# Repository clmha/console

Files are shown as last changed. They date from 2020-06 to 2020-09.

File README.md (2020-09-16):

# Console
Ce projet est une console (code de projet CN1) avec des prises électriques faite sur-mesure pour aller en arrière du canapé. Il est inspiré du projet "Console Table" de [Build Something](https://www.buildsomething.com/plans/P1CFF7829247E55CF/Console-Table).

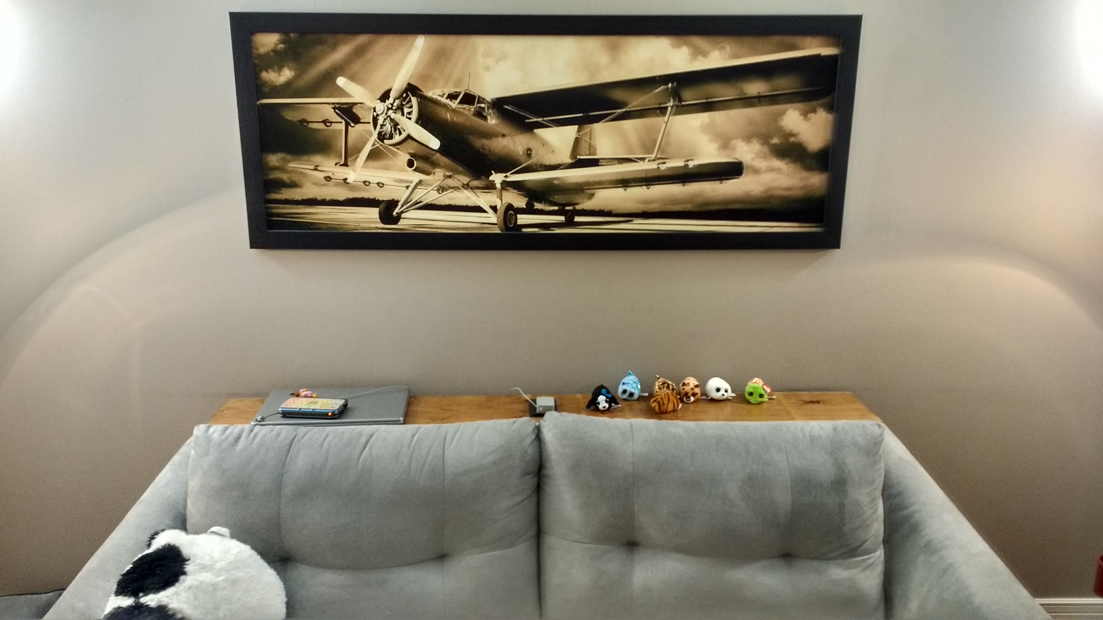
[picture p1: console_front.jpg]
Face de la Console

*Figure 1 - Vue de face*

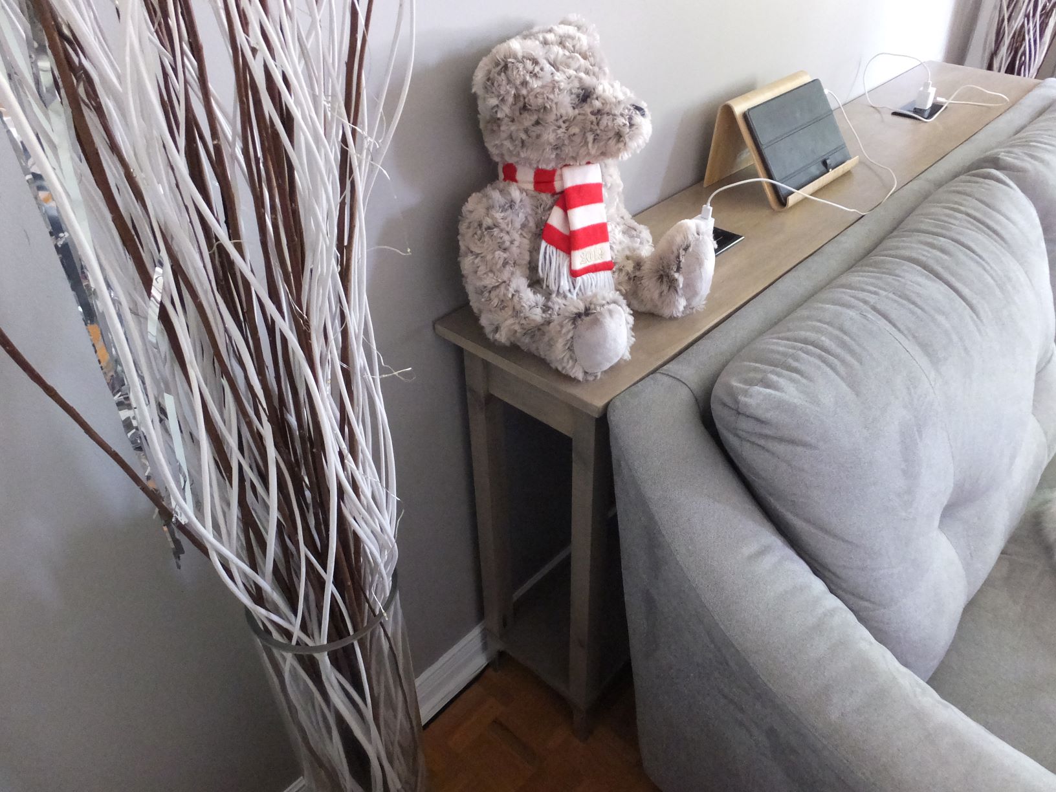
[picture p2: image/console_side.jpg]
Côté de la Console

*Figure 2 - Vue de côté*

Vous trouverez la liste des matériaux et de la quincaillerie nécessaires au sein de [CN1-MFG-001]. Hormi les outils de base (p. ex. ruban à mesurer), vous aurez également besoin des items suivants :

* Gabarit pour faire des trous en angle;
* Perceuse/visseuse;
* Scie circulaire pour la découpe grossière des panneaux;
* Banc de scie pour la découpe finale des panneaux;
* Scie à onglet pour découper précisement les lattes et les planches;
* Scie sauteuse pour découper les trous pour les prises électriques.

# Liste des documents
* CN1-ASY-001.pdf : dessin d'ensemble du projet avec la liste des pièces;
* CN1-MFG-001.pdf : le coût du projet;
* CN1-PRT-XYZ.pdf : le dessin de définition de la pièce numéro XYZ (notez que les pièces triviales n'ont pas de dessin de définition);
* CN1-REQ-001.pdf : le cahier des charges du projet.

# Environnement de développement
* Windows 10 comme système d'exploitation;
* QCAD Professional pour les dessins techniques;
* LibreOffice 6.* pour les documents;
* PDFtk pour manipuler les fichiers PDF;
* MinGW (mingw32-base-bin 2013072200) pour les outils de développement de base.

# Construire les artefacts
Avec l'environnement de développement correct, il vous suffit de lancer la commande "mingw32-make" depuis une invite de commande cmd.exe à la racine du projet et les documents seront générés dans le répertoire "build".

En cas d'erreurs "'X' n'est pas reconnu en tant que commande interne ou externe [...]", vérifiez que les exécutables de LibreOffice, QCAD, PDFtk et MinGW sont dans votre PATH.

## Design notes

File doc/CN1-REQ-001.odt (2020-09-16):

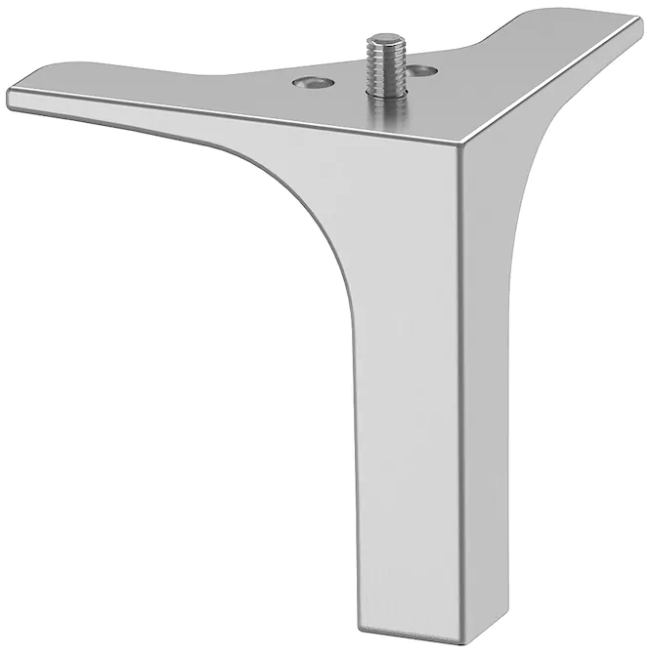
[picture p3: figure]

Figure 2 NANNARP aluminium (IKEA P/N 502.935.95) [IK00]

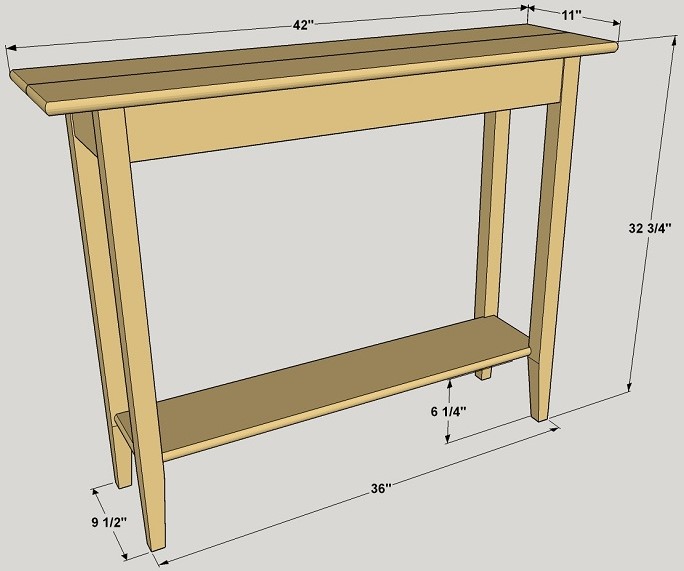
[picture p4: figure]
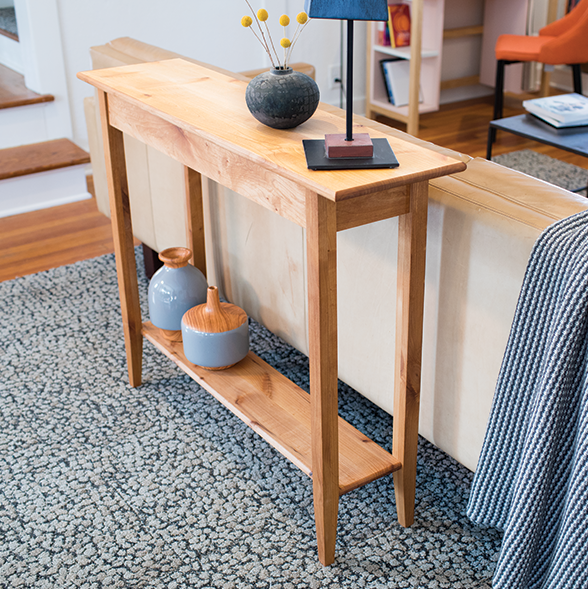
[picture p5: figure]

Figure 1 Exemple de console [BS00]

Cahier des charges

CN1-REQ-001 MOD 2

Clément Hamel

2020-09-16

# Définitions

po Pouce

# Références

BS00: buildsomething, Console Table, 2017, https://www.buildsomething.com/plans/P1CFF7829247E55CF/Console-Table

IK00: IKEA, IKEA, 2020, https://www.ikea.com/

# Vision

Nous souhaitons une console pour aller en arrière du canapé dans le salon et avec des prises électriques pour nous permettre de recharger nos appareils électroniques. Comme exemple ce qui nous plairait, il y a la conception illustrée dans la Figure 1.

# Exigences

## Longueur

La longueur du meuble doit être de 69 po, comme notre canapé.

## Hauteur

La hauteur du meuble doit être de 31 po afin que le plateau soit à la même hauteur que le dos de notre canapé.

## Profondeur

La profondeur du meuble doit être de :

- au moins 8 po (±1/8) afin de pouvoir poser les pattes; et
- au plus 10 po afin de ne pas trop empiéter l’espace du salon.

## Structure

### Portée

La portée des tablettes/plateaux entre leurs supports doit être inférieure ou égale à 36 po.

### Dépassement

Les tablettes/plateaux ne doivent pas dépasser de leurs supports plus que leur épaisseur.

## Finition

### Pattes

Le meuble doit avoir les pieds similaires à ceux de nos autres meubles du salon afin d’avoir un salon à l’apparence consistante (c.f. Figure 2).

### Bois

Le meuble doit avoir une couleur et un motif similaire à nos autres meubles du salon afin d’avoir un ensemble à l’apparence consistante.

## Électricité

Le meuble doit avoir au moins deux prises électriques accessible depuis les personnes assises dans le canapé afin qu’ils puissent recharger leurs appareils électroniques personnels.

## Sécurité

Les chats ne doivent pas pouvoir accéder aux parties sous haute-tension du meuble. Ils aiment bien se promener sous le meuble, et nous ne souhaitons pas que leur curiosité cause leur mort.

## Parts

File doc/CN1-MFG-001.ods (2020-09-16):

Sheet: Planifié
Item | Qté | Source | Prix unitaire HT | Rabais | Prix HT | Remarques
Bande de chant érable 13/16"x25' | 2 | BMR | 6,98 $ |  | 13,96 $
Panneau de particules plaqué érable 11/16"x4'x8' | 1 | BMR | 56,99 $ |  | 56,99 $
Latte 2x2x8’ de pin blanc | 2 | BMR | 5,99 $ |  | 11,98 $
Planche 1x4x6' de pin blanc | 1 | BMR | 4,99 $ |  | 4,99 $
Planche 1x4x8’ de pin blanc | 1 | BMR | 6,99 $ |  | 6,99 $
Boîte électrique rectangulaire avec oreilles 2"x3"x2 1/2" | 2 | (Estimation) | 3,00 $ |  | 6,00 $
Prise électrique double | 2 | (Estimation) | 2,00 $ |  | 4,00 $
Plaque électrique pour prise double | 2 | (Estimation) | 1,50 $ |  | 3,00 $
Cordon d’alimentation d’ordinateur 6 pi | 1 | (Estimation) | 10,00 $ |  | 10,00 $
Fil électrique AWG14 10 m | 1 | (Estimation) | 35,00 $ |  | 35,00 $
Patte Nannarp 2 mcx | 2 | IKEA | 10,00 $ |  | 20,00 $
Pré-teinture 1 qt | 1 | (Estimation) | 17,00 $ |  | 17,00 $
Teinture couleur de base 1 qt | 1 | (Estimation) | 17,00 $ |  | 17,00 $
Teinture couleur naturel 1 qt | 1 | (Estimation) | 17,00 $ |  | 17,00 $ | Pour pouvoir adapter la couleur de base aux différentes essences de bois.
Vernis transparent 1 qt | 1 | (Estimation) | 23,00 $ |  | 23,00 $
Vis à métal #6 5/8" ~10 mcx | 1 | (Estimation) | 2,89 $ |  | 2,89 $
Vis pour perçage à angle à filetage grossier #8 1" BT100 | 1 | (Estimation) | 7,00 $ |  | 7,00 $
Vis pour perçage à angle à filetage grossier #8 1 1/4" BT100 | 1 | (Estimation) | 7,50 $ |  | 7,50 $
Sous-total HT |  |  |  |  | 264,30 $
TPS |  |  |  |  | 13,22 $
TVQ |  |  |  |  | 26,36 $
Total TTC |  |  |  |  | 303,88 $

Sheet: TQC
Item | Qté | Source | Prix unitaire HT | Rabais | Prix HT | Remarques
Bande de chant érable 13/16"x25' | 1 | BMR | 6,98 $ | 10,00% | 6,28 $
Bande de chant érable 13/16"x25' | 1 | BMR | 6,98 $ |  | 6,98 $
Panneau de particules plaqué érable 11/16" |  | (Rebus) |  |  | 0,00 $
Latte 2x2x8’ de pin blanc | 2 | BMR | 6,29 $ |  | 12,58 $
Planche 1x4x6' de pin blanc | 2 | BMR | 4,99 $ | 10,00% | 8,98 $
Planche 1x4 de pin blanc |  | (Rebus) |  |  | 0,00 $
Boîte électrique rectangulaire avec oreilles 2"x3"x2 1/2" | 2 | BMR | 2,98 $ | 10,00% | 5,36 $
Prise électrique double | 2 | BMR | 1,89 $ | 10,00% | 3,40 $
Plaque électrique pour prise double | 2 | BMR | 1,49 $ | 10,00% | 2,68 $
Cordon d’alimentation d’ordinateur |  | (Rebus) |  |  | 0,00 $
Fil électrique AWG14 |  | (Rebus) |  |  | 0,00 $
Patte Nannarp |  | (Rebus) |  |  | 0,00 $
Pré-teinture |  | (Rebus) |  |  | 0,00 $
Teinture couleur de base |  | (Rebus) |  |  | 0,00 $
Teinture couleur naturel |  | (Rebus) |  |  | 0,00 $ | Pour pouvoir adapter la couleur de base aux différentes essences de bois.
Vernis transparent |  | (Rebus) |  |  | 0,00 $
Vis à bois #6 3/4" |  | (Rebus) |  |  | 0,00 $
Vis pour perçage à angle à filetage grossier #8 1" |  | (Stock) |  |  | 0,00 $
Vis pour perçage à angle à filetage grossier #8 1 1/4" |  | (Stock) |  |  | 0,00 $
Sous-total HT |  |  |  |  | 46,27 $
TPS |  |  |  |  | 2,31 $
TVQ |  |  |  |  | 4,62 $
Total TTC |  |  |  |  | 53,20 $

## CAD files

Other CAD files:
drawing/CN1-PRT-001.dxf
drawing/CN1-ASY-001.dxf

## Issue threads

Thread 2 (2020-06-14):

Dimensions

clmha, 2020-06-14:
Le requis de hauteur de la Console n’est pas respecté car j’avais supposé que les dimensions nominales du bois étaient égales au dimensions réelles. Comme un 1×10 po. (nominal) mesure en réalité 3/4×9 ¼ po., cela fait une erreur de ½ po. au final. J’ai été chanceux, la tablette affleure quand même le dos du canapé.

clmha, 2020-09-16:
Le nouveau modèle, #7, a utilisé les dimensions réelles des matériaux mais ne respecte toujours pas exactement l'exigence de hauteur de 31 po (hauteur du canapé), car nous avons décidé lors de la conception que la tablette supérieure serait plus plus basse de 1/2 po pour cacher d’éventuelles imprécisions.

La hauteur planifiée est donc de 30 1/2 po, mais la hauteur mesurée après assemblage est de 30 5/8 po à cause de l'imprécision des dimensions des pattes.

Les plans devraient être mis à jour avec des pattes 1/8 po plus grandes.

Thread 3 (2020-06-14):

Position des pattes

clmha, 2020-06-14:
Pour que la Console touche au mur, les pattes devraient être écartées du bord d’une distance égale à l’épaisseur des moulures.

clmha, 2020-09-16:
Le nouveau modèle, #7, a une tablette supérieure qui surplombe la tablette inférieure de 1 po de chaque côté. Comme les moulures font approx. 15/16 po d'épaisseur, cela permet au bord de la tablette supérieure de toucher le mur avant que la tablette inférieure ou les pattes touchent la moulure.

Closed 2020-09-16.

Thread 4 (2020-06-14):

Résistance en torsion

clmha, 2020-06-14:
La structure a une résistance insuffisante en torsion car seule la planche du dessus lie les deux montants. Dans une future itération, des madrier pourraient être utilisés pour augmenter la résistance en torsion.

clmha, 2020-09-16:
Le nouveau modèle, #7, a une résistance en torsion améliorée en utilisant :
 * des lisses ; et
 * une tablette inférieure en une seule partie.

Closed 2020-09-16.

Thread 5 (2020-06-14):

Espace non-fini

clmha, 2020-06-14:
Comme le dos du canapé n’est pas droit, il est possible d'entrevoir l’intérieur (non-teint) de la Table lorsque l’on regarde le côté.

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

Un panneau dur l'aurait rendu plus cosmétique.

clmha, 2020-09-16:
Le nouveau modèle, #7, n'a pas de panneau dur pour cacher l'intérieur mais a été fini entièrement.

Closed 2020-09-16.

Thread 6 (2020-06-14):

Couleur incorrecte

clmha, 2020-06-14:
La couleur finale n'est pas similaire à celle des autres meubles du salon (gris):

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

clmha, 2020-09-16:
Le problème de couleur a été corrigé sur le nouveau modèle, #7, en appliquant deux couches d'un mélange 1:1 de Min Wax Gris Classique et Naturel.

Closed 2020-09-16.

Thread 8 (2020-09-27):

Sous-spécification des positions des lisses

clmha, 2020-09-27:
Au sein du dessin d'ensemble, les positions des lisses (pièces no 4 et 5) sont sous-spécifiées. Il faut illustrer qu'elles sont placées au centre des montants (pièces no 3) pour lever l’ambiguïté.

clmha, 2020-09-27:
Une cote a été ajoutée dans le dessin d'ensemble. Avec les dimensions des lisses, cela permet de spécifier quelles sont placées au centre des montants.

Closed 2020-09-27.

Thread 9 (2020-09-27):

Dimensions d'ensemble

clmha, 2020-09-27:
Les dimensions d'ensemble manquent au dessin d'ensemble CN1-ASY-001. Sans celles-ci, il n'est pas possible de vérifier les exigences sur les dimensions.

clmha, 2020-09-28:
Les dimensions sont maintenant affichées dans le dessin d'ensemble et devraient toujours être là lors de la prochaine relâche.

Closed 2020-09-28.

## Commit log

2020-06-14 Importation des documents manuscrits et Google Docs
2020-06-14 Ajout des photos et MàJ du README
2020-06-16 Dessin préliminaire et cahier des charges
    Clarifie la vision et les exigences dans le cahier des charges et lui donne un numéro de de document correct.
    Remplace le dessin d'ensemble manuscrit par le dessin préliminaire du nouveau modèle, lui aussi avec un numéro de document correct.
    [CN1-ASY-001.dxf]
2020-06-16 Ajout des lisses
    [CN1-ASY-001.dxf]
2020-06-21 Correction de la hauteur
    Raccourcit les montants de 26 po à 25 1/8 po.
    [CN1-ASY-001.dxf]
2020-06-21 Augmentation de la partie suspendue
    Augmente la partie suspendue autour du meuble de 3/4" à 1" afin que les pattes ne touchent pas les moulures du mur lorsque le dessus de la console est accoté contre le mur.
    Cette révision change aussi les largeurs des tablettes pour des tailles de planches courantes (9 1/4", 11 1/4").
    [CN1-ASY-001.dxf]
2020-06-24 Dessin d'ensemble et exigences validées
    Cette révision enlève le filigrane "brouillon" du cahier des charges et finalise le dessin d'ensemble en ajoutant les emplacements pour les prises électriques, la liste des pièces mais aussi les méthodes de fixation.
    [CN1-ASY-001.dxf]
2020-06-24 Ré-organisation des dossiers
    Sépare les fichiers entre les fichiers bureautique (doc/), les dessins (drawing/) et les images (image/) d'après le standard de facto du projet computerdesk (CD1).
    Met à jour le README.md pour le nouvel emplacement des images.
    [CN1-ASY-001.dxf]
2020-07-08 Ajout du coût des produits vendus
    [CN1-MFG-001.ods]
2020-07-11 MàJ des dépenses
    [CN1-MFG-001.ods]
2020-07-25 Mise à jour du coût
    Bande chant supplémentaire et un peu plus de rebus.
    [CN1-MFG-001.ods]
2020-08-08 Ajout du dessin de définition de la tablette supérieure
    [CN1-PRT-001.dxf]
2020-09-16 Ajout du coût planifié et MàJ du TQC
    En profite pour ajouter les vis utilisées pour fixer les plaques électriques et le coût du câblage électrique.
    [CN1-MFG-001.ods]
2020-09-16 Ajout manuel des révisions
    En profite pour régler l'affichage de la patte Ikea dans le cahier des charges (CN1-REQ-001).
    [CN1-ASY-001.dxf, CN1-PRT-001.dxf]
2020-09-16 MàJ des photos et du README
